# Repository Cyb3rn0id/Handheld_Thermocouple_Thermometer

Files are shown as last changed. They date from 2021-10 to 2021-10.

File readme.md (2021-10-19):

## Handheld Thermocouple Thermometer

This is a project for making an Handheld Thermometer using a K-type Thermocouple. You can read from 0°C up to 1023.75°C depending on the used thermocouple (most thermocouple reads from 0 t 400°C). You cannot read negative temperatures.

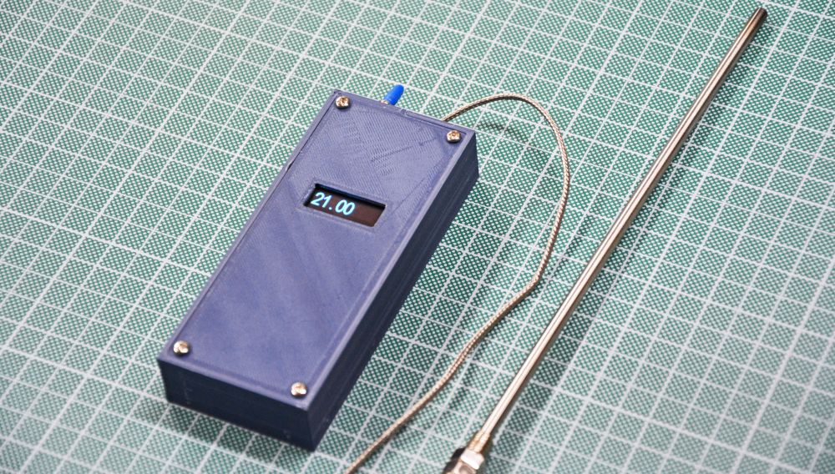
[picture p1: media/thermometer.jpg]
Thermometer


Microcontroller used is an ATtiny85 on the Digistump Digispark. Thermocouple is connected through a MAX6675 amplifier. Readings are showed on a 0.91" (128x32) OLED display. Whole thing is powered using a 9V battery connected on Vin pin of the Digispark. Digispark has a 5V regulator on board and a 5V output used for powering the amplifier and the oled. 

>Even if the OLED controller works at 3.3V is safe powering the display at 5V. Those OLEDS have a voltage regulator on board that step down to 3.3V. SDA and SCL lines are connected on display to 3.3V through pull-up resistors: remember that I2C pulls only lines to GND and when an high logic level must be sent, device put the gpio in high impedance so the logic level is given by the pullup resistor.

### Considerations

A thermocouple is made for reading high temperatures in critical ambients, so if you need accurate and precise readings, maybe a thermocouple is not good for you and you should consider using a PT100 instead coupled to a MAX31865 or similar

### Programming the Digispark

I wrote a tutorial [here](https://www.settorezero.com/wordpress/dispositivi-usb-sulla-punta-di-un-dito-il-digispark/). After you prepared the Arduino IDE for programming the Digispark, you must install those 3 libraries:

- [TinyWireM by Adafruit](https://github.com/adafruit/TinyWireM)
- [Tiny4kOLED by Stephen Denne (datacute)](https://github.com/datacute/Tiny4kOLED)
- [MAX6675 Library by Adafruit](https://github.com/adafruit/MAX6675-library)

### Connections

- 9V Battery : (+) => Digispark Vin, (-) => GND
- MAX6675 to Digispark: SCK=>D4, CS=>D3, SO=>D1, VCC=>5V
- 0.91" OLED to Digispark: SCL=>D2, SDA=>D0, VCC=>5V

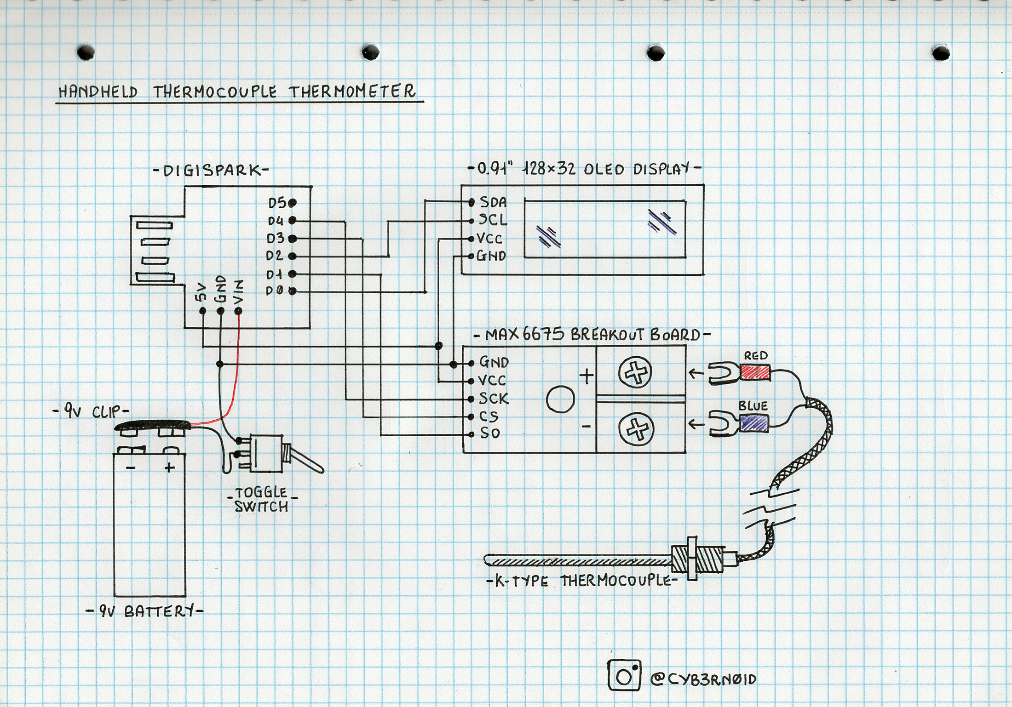
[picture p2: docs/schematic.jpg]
hand-drawn schematic


- Thermocouple has a positive (red) and negative (blue) wire: connect them properly.
- Put a Switch on a lead of the battery for turning the thermometer on/off.

### Enclosure

I've designed an enclosure for the thermometer: you can find STL and STEP files in the [cad folder](./cad).
Enclosure is [made of 3 parts](./media/enclosure_1.jpg).

Every electronic component has his own slot in the enclosure and lever switch goes through the frontal hole. Thermocouple amplifier, Digispark and Battery with his clip will go in the box (bigger part). OLED display will go under the lid. [See this picture](./media/enclosure_2.jpg).

Thermocouple cable will pass through the frontal slot so you absolutely must not cut the terminals. The small 3D-printed piece [will fit the slot closing it](./media/enclosure_3.jpg).

### Materials
Thermometer Components are [showed here](./media/parts.jpg).

Following links are sponsored and only valid for Italian users, anyway you can use them for reference.

- [Digispark](https://amzn.to/3jfEXZZ) - Warning: maybe is not the original one, so take this link only for reference
- [MAX6675 Breakout Board](https://amzn.to/3iQSKG3)
- [K Thermocouple (2m cable, long probe, max 400°C)](https://amzn.to/2YKbEHv)
- [Oled Display 0.91" 128x32](https://amzn.to/3BI8nak)
- [Lever Switch](https://amzn.to/30f1Q8V)
- [9V Battery](https://amzn.to/3FQUnxt)
- [9V clip](https://amzn.to/3oSUQsM)
- [M3 Inserts](https://amzn.to/3iU5vQ2) (you need only 4)
- [M3 Screws kit](https://amzn.to/2YIq7nI) (you need only 4)

### Links
- [Hackaday.io](https://hackaday.io/project/182165-handheld-thermocouple-thermometer)
- [Hackster](https://www.hackster.io/CyB3rn0id/handheld-thermocouple-thermometer-121893)

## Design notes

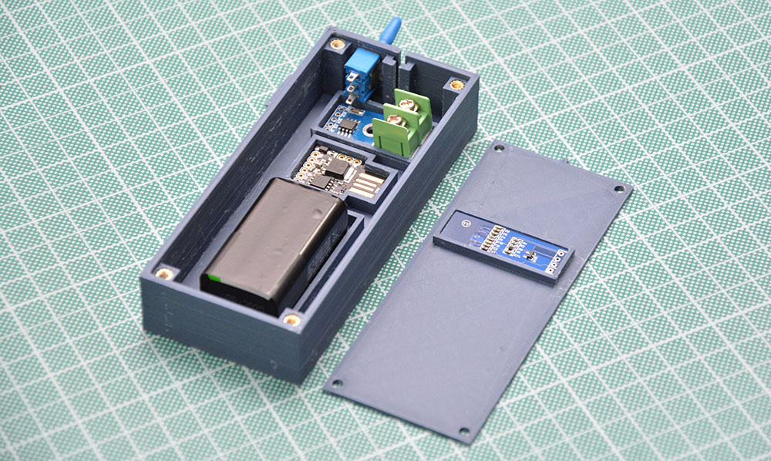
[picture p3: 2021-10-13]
media/enclosure_2.jpg

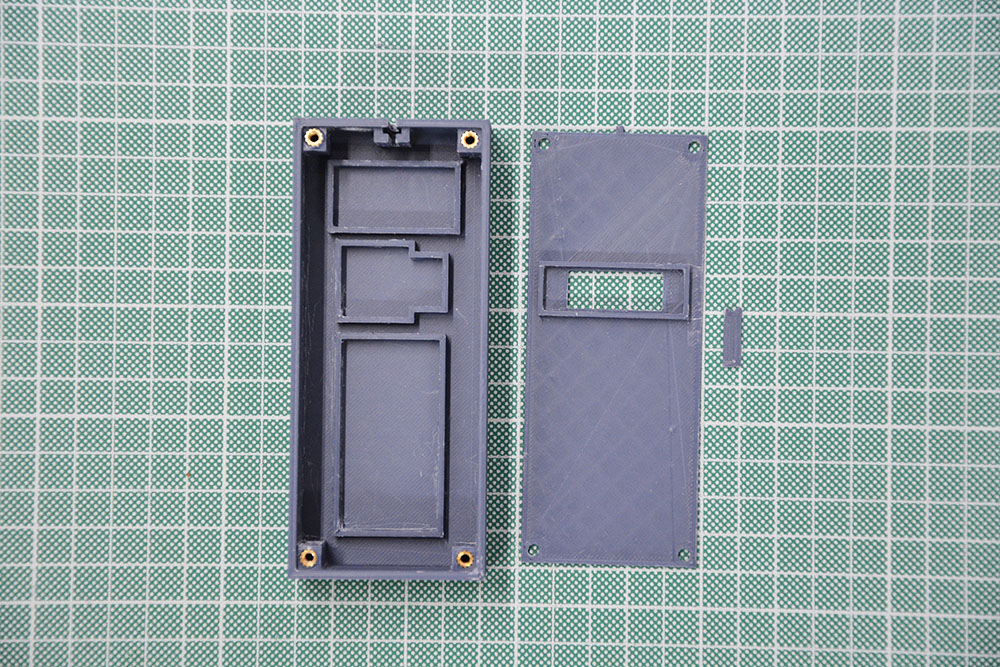
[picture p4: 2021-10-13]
media/enclosure_1.jpg

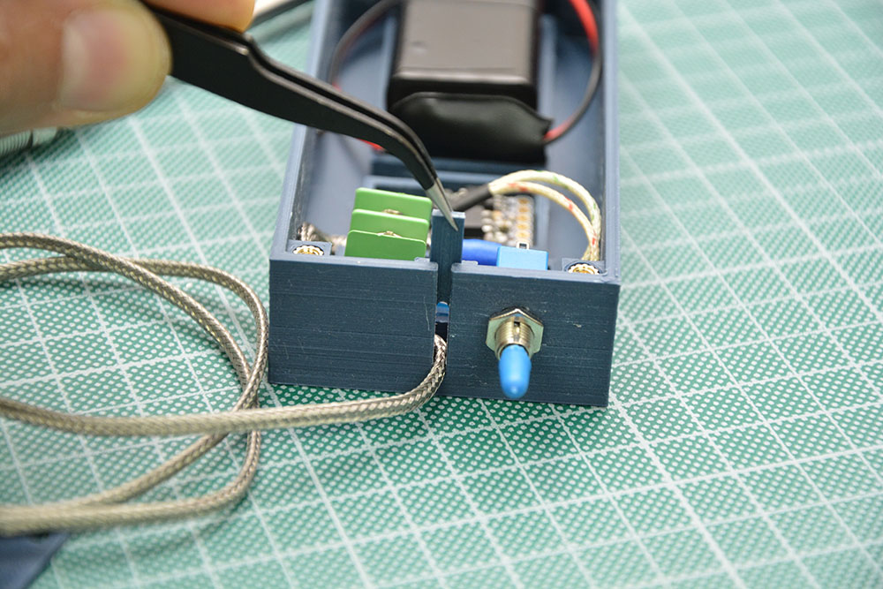
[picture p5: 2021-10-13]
media/enclosure_3.jpg

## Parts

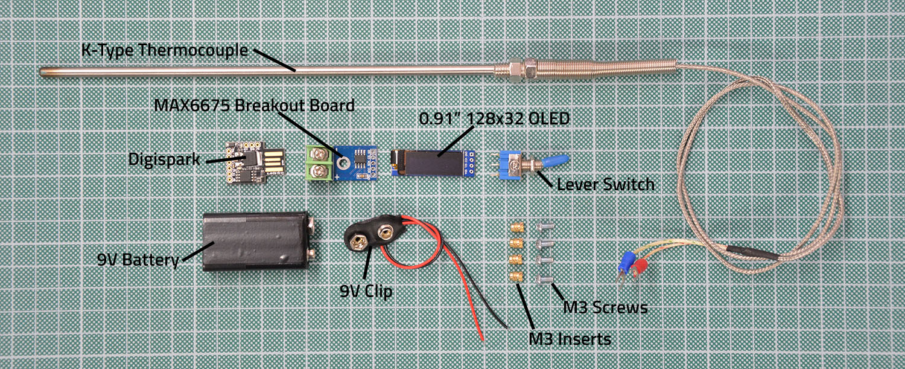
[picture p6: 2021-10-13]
media/parts.jpg

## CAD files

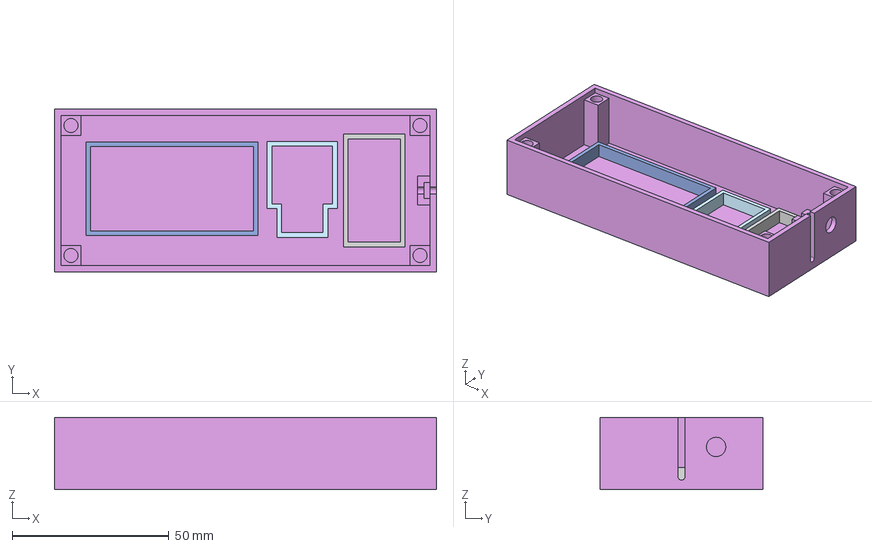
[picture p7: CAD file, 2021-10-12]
cad/step/enclosure_box.step
122.0 x 52.0 x 23.0 mm

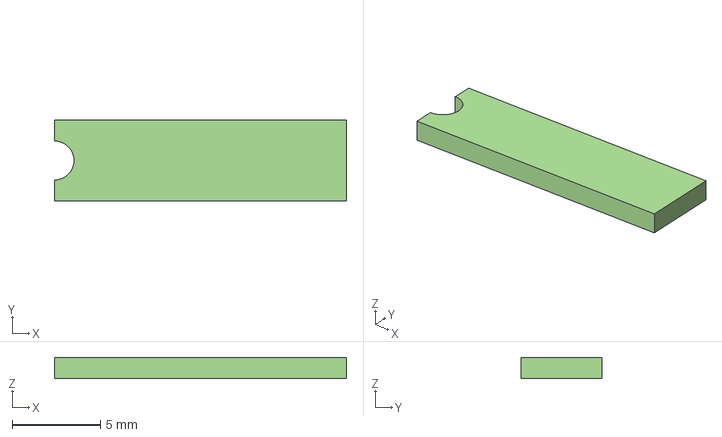
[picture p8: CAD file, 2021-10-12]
cad/step/enclosure_probe_slot_cover.step
16.5 x 4.60 x 1.20 mm

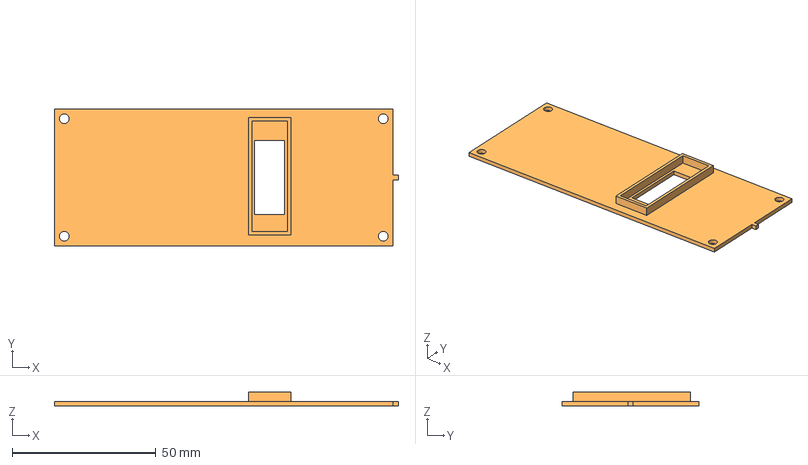
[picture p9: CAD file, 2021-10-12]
cad/step/enclosure_lid.step
119.5 x 47.6 x 4.80 mm

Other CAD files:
cad/stl/enclosure_box.stl
cad/stl/enclosure_lid.stl
cad/stl/enclosure_probe_slot_cover.stl

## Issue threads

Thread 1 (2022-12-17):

.step files fail to translate

Nick-Z0, 2022-12-17:
Hi, I try to import the .step files to onshape and fusion360 but both programs fail to translate the files. Can it be that they are corrupted or something? I want to edit the case and make it a bit rounder.

Nick-Z0, 2022-12-21:
Never mind, I did not download the files correctly.

Closed 2022-12-21.

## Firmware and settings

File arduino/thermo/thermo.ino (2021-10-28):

/*
 * Handheld Thermocouple Thermometer
 * by Giovanni 'Cyb3rn0id' Bernardo
 * https://www.settorezero.com
 * 
 *
 * Used Digistump Digispark (ATtiny85)
 * 
 * Libraries to be installed:
 * - TinyWireM by Adafruit
 * - Tiny4kOLED by Stephen Denne (datacute)
 * - MAX6675 by Adafruit
 *
 * Connections:
 * 9V Battery to Vin/GND on Digispark
 * MAX6675 to Digispark: SCK=>P4, CS=>P3, SO=>P1, VCC=>5V
 * 0.91" OLED to Digispark: SCL=>P2, SDA=>P0, VCC=>5V
 *
 */
 
// Digispark has his TinyWire library installed but doesn't works well with
// the display (my issue #39: https://github.com/datacute/Tiny4kOLED/issues/39)
// so it's needed to include TinyWireM from Adafruit
#include <TinyWireM.h>

// Defining this constant, 'print' function will be disabled, saving space on the ATtiny
// (anyway if you don't use print function, will not included anyway). Print function 
// must be not used since there will be not enough space in the flash memory
#define TINY4KOLED_NO_PRINT
#include <Tiny4kOLED.h>

// MAX6675 library by Adafruit
#include "max6675.h"

// Include the big font coming with the Tiny4KOLED library. This font contains only
// numbers, minus and dots/commas
#include "font16x32digits.h"
const DCfont *currentFont = FONT16X32DIGITS;

// MAX6675 breakout board connections to Digistump
// MAX6675 thermocouple(SCLK, CS, S0);
MAX6675 thermocouple(4, 3, 1); // CLK, CS, DO

void setup() 
  {
  oled.begin();
  //oled.enableChargePump();
  oled.setFont(currentFont);
  //oled.setRotation(0);
  oled.clear();
  oled.on();
  // Switch the half of RAM that we are writing to, to be the half that is non currently displayed
  oled.switchRenderFrame();
  delay(500);
  }

void loop() 
  {
  oled.clear();
  double t = thermocouple.readCelsius(); // read thermocouple
  int t1 = (int)t; // temperature as integer
  double dec = t - t1; // decimal part as 0.xx
  int t2 = (int)(dec*100); // decimal part as integer (0.xx => xx)

  // Notice: MAX6675 can read from 0 to 1023.75°C
  // So there will be not negative temperatures. 
  // Anyway I included this part since can be useful for other applications
  
  // If negative temperature, print minus sign and convert number in positive
  /*
  if (t1<0)
    {
    oled.write('-'); // print minus sign
    t1*=-1; 
    t2*=-1;  
    }
   */
  int i;
  // Print integer part
  if (t1>99)
    {
    i = t1/100; // first digit
    oled.write(i+'0'); // print the number in ascii format ('0' will be interpreted as ascii code of '0')
    t1=t1-(i*100); // remaining tenths
    if (t1<10) // remaining part can be 0x if the number was 10x
      {
      // so I must write the 0
      oled.write('0');    
      }
    }
    
  if (t1>9) // tenths
      {
      // tenth
      i=t1/10;
      oled.write(i+'0');     
      t1=t1-(i*10); // remaining units
      }
      
   oled.write(t1+'0'); // print units

   oled.write('.'); // decimal separator

    // Decimal part is always 00, 25, 50 or 75 since
    // the MAX6675 has only 2 bits for decimal part (quarter of a grade)
    if (t2>0) // decimal part is not zero
      {
      // tenth
      i=t2/10;
      oled.write(i+'0');     
      t2=t2-(i*10); // units
      oled.write(t2+'0'); 
      }
    else // is 0
      {
      oled.write('0');
      oled.write('0');
      }
  
  oled.switchFrame();
  delay(1000); // give some delay between readings
  }

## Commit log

2021-10-12 added cads and max6675 datasheet
    [enclosure_box.step, enclosure_box.stl, enclosure_lid.step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]
2021-10-18 added schematic
2021-10-19 added library links and schematic image
2021-10-28 corrected "i was not declared in this scope"
    thx to Reimund Hörnemann on hackaday
    [thermo.ino]
